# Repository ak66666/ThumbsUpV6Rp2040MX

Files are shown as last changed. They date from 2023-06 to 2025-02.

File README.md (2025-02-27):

# ThumbsUp! v6 RP2040-based keyboard for MX and ALPS switches

Multilevel 44 Key Split Contoured Keyboard.
2-key Thumb Cluster
   
* RP2040 is soldered on the boards.
* TRS (3-wire) audio cable to connect the halves.
* Hot swap sockets for MX switches, the ALPS need to be soldered in.
* USB-C connectors.
* Connects to computer from either side, halves could be used separately.

Board needs 3D printed switch plates: https://github.com/ak66666/ThubmsUpSwitchPlates

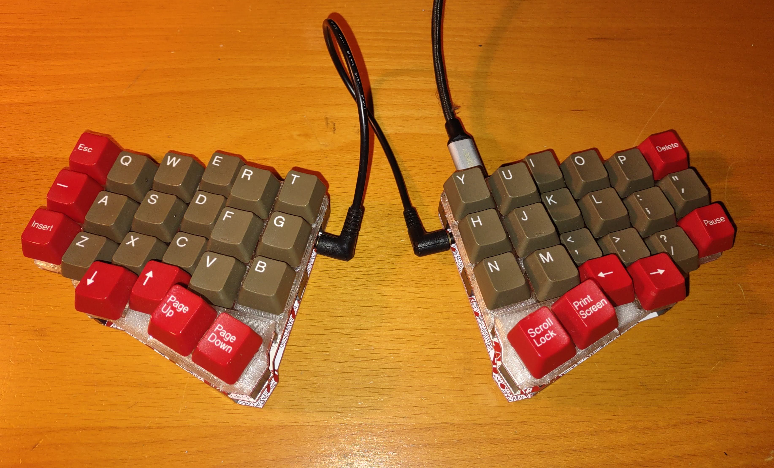
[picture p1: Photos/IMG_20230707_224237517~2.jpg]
Main view

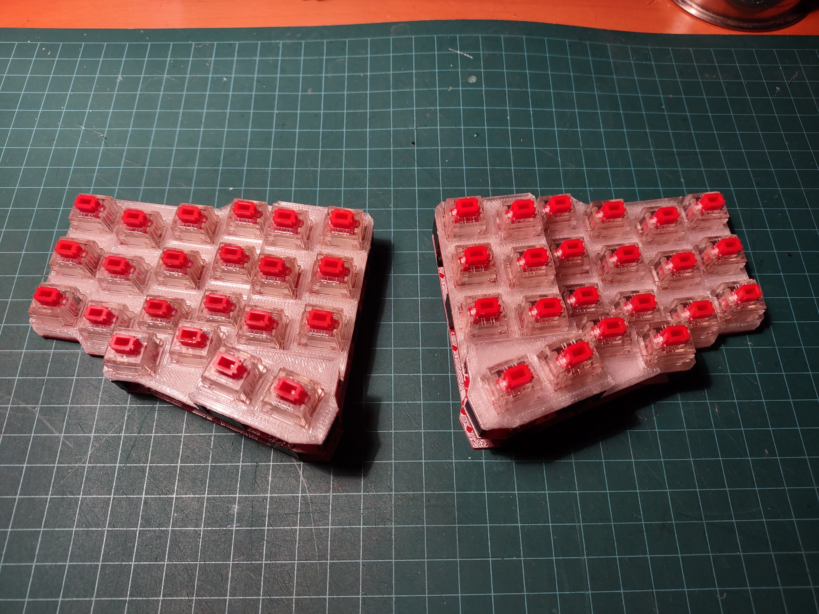
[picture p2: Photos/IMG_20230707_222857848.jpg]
ALPS Switches view


Other pictures in Photos folder.

# Firmware

Please refer to this article:
https://thumbsupkeyboards.blogspot.com/2024/02/source-files-and-default-firmware.html

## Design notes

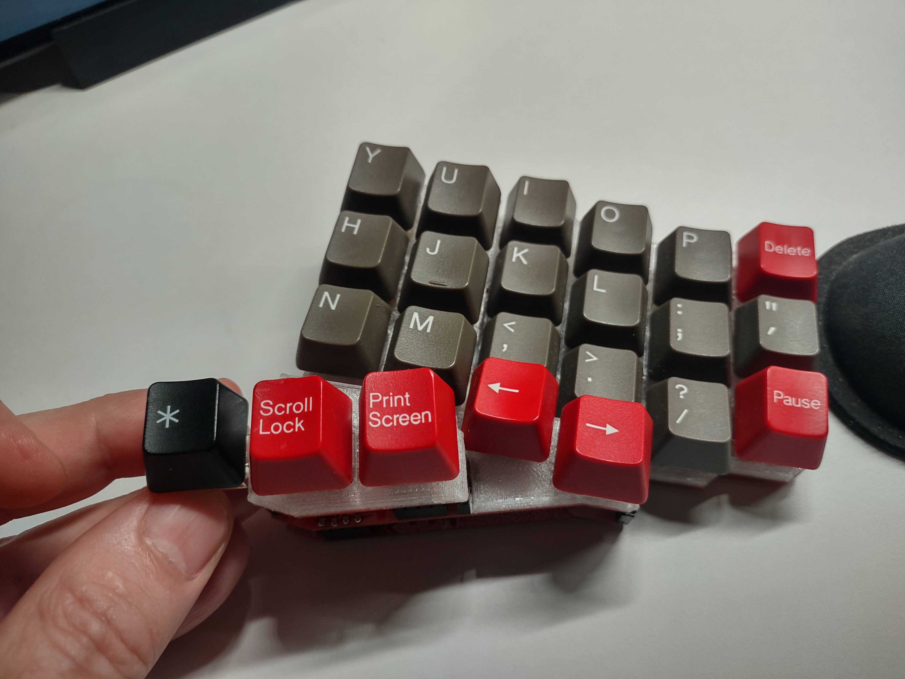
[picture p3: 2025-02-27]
Photos/IMG_20230818_104513918_HDR.jpg

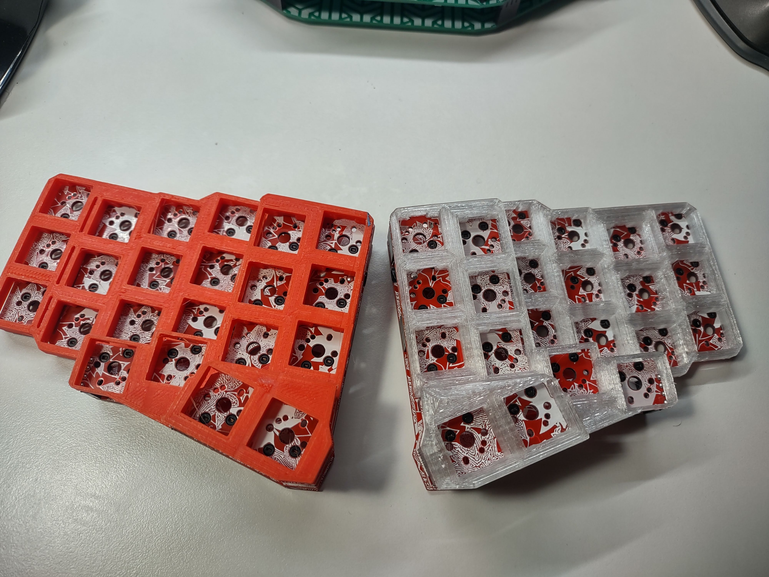
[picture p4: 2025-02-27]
Photos/IMG_20230814_161227283_HDR.jpg

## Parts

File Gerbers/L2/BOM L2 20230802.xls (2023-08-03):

Comment | Designator | Footprint | JLCPCB Part #
W25Q128JVSIM | IC2 | SOIC127P790X216-8N | C2613930
USB_C_Receptacle_USB2.0 | J32 | USB_C_Receptacle_Palconn_UTC16-G | C2927037
27pF | C5,C4 | C_0402_1005Metric | C1557
AMS1117-3.3_SOT223 | U1 | SOT229P700X180-4N | C6186
27.4 | R2,R1 | R_0402_1005Metric | C274349
10uF | C9 | C_0402_1005Metric | C15525
0.1uF | C17,C16,C15,C14,C13,C10,C7,C6,C2 | C_0402_1005Metric | C1525
5.1K | R9,R8,R4,R17 | R_0402_1005Metric | C25905
100uF | C11 | C_1210_3225Metric | C16133
1uF | C12,C3 | C_0402_1005Metric | C52923
Polyfuse | F1 | Fuse_1206_3216Metric | C2836286
1k | R6 | R_0402_1005Metric | C11702
RP2040 | IC1 | QFN40P700X700X90-57N-D | C2040
10K | R3,R7 | R_0402_1005Metric | C25744
ABLS-12.000MHZ-B4-T | Y1 | HC-49S-SMD | C2901753

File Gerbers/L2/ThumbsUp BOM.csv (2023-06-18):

Id | Designator | Package | Quantity | Designation | Supplier and ref
1 | G*** | LeavesW311 | 1 | LOGO
2 | MX20 | MX-1U-NoLED_HotSwap | 1 | SwG
3 | U1 | SOT229P700X180-4N | 1 | AMS1117-3.3_SOT223
4 | C11 | C_1210_3225Metric | 1 | 100uF
5 | RUN1,BOOTSEL1 | BUTT4 | 2 | BUTT-4
6 | R17,R4 | R_0402_1005Metric | 2 | 5.1K
7 | J50,J39,J45,J16 | PinHeader_1x04_P2.54mm_Vertical | 4 | Raiser_Male
8 | MX16 | MX-1U-NoLED_HotSwap | 1 | SwF
9 | MX21 | MX-1U-NoLED_HotSwap | 1 | SwB
10 | MX19 | MX-1U-NoLED_HotSwap | 1 | SwT
11 | MX17 | MX-1U-NoLED_HotSwap | 1 | SwV
12 | MX15 | MX-1U-NoLED_HotSwap | 1 | SwR
13 | MX14 | MX-1U-NoLED_HotSwap | 1 | SwLALT
14 | MX10 | MX-1U-NoLED_HotSwap | 1 | SwLWIN
15 | R2,R1 | R_0402_1005Metric | 2 | 27.4
16 | R9,R8 | R_0402_1005Metric | 2 | 5.1k
17 | R7 | R_0402_1005Metric | 1 | 10K
18 | R6 | R_0402_1005Metric | 1 | 1k
19 | R3 | R_0402_1005Metric | 1 | 10k
20 | C17,C16,C15,C14,C13,C10,C7,C6,C2 | C_0402_1005Metric | 9 | 0.1uF
21 | C12,C3 | C_0402_1005Metric | 2 | 1uF
22 | C9 | C_0402_1005Metric | 1 | 10uF
23 | C5,C4 | C_0402_1005Metric | 2 | 27pF
24 | J32 | USB_C_Receptacle_Palconn_UTC16-G | 1 | USB_C_Receptacle_USB2.0
25 | J3 | PinSocket_1x04_P2.54mm_Vertical | 1 | Conn_01x04_Female
26 | J36 | STX35013N | 1 | STX-3501-3N
27 | J17,J9,J13 | PinSocket_1x04_P2.54mm_Vertical | 3 | Raiser_Female
28 | J1,J8,J7 | PinHeader_1x04_P2.54mm_Vertical | 3 | Conn_01x04_Male
29 | Y1 | HC%2f49US-(AT49)_1 | 1 | ABLS-12.000MHZ-B4-T
30 | IC2 | SOIC127P790X216-8N | 1 | W25Q128JVSIM
31 | IC1 | QFN40P700X700X90-57N-D | 1 | RP2040
32 | F1 | Fuse_1206_3216Metric | 1 | Polyfuse

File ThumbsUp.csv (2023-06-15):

Id | Designator | Package | Quantity | Designation | Supplier and ref
1 | RUN,BOOTSEL | TL1016AAF220QG | 2 | TL1016AAF220QG
2 | IC1 | QFN40P700X700X90-57N-D | 1 | RP2040
3 | D25,D44,D43,D42,D41,D40,D39,D38,D37,D36,D35,D34,D33,D32,D31,D30,D29,D28,D27,D26,D24,D23,D22,D21,D20,D19,D18,D17,D16,D15,D14,D13,D12,D11,D10,D9,D8,D7,D6,D5,D4,D3,D2,D1 | D_SOD-123 | 44 | D_Small
4 | Y1 | HC%2f49US-(AT49)_1 | 1 | ABLS-12.000MHZ-B4-T
5 | R3 | R_0805_2012Metric | 1 | 10k
6 | IC2 | SOIC127P790X216-8N | 1 | W25Q128JVSIM
7 | C9,C11 | C_0805_2012Metric | 2 | 10uF
8 | C7,C6,C2,C1,C17,C16,C15,C14,C13,C10 | C_0805_2012Metric | 10 | 0.1uF
9 | C5,C4 | C_0805_2012Metric | 2 | 27pF
10 | C3,C12 | C_0805_2012Metric | 2 | 1uF
11 | U1 | SOT-223-3_TabPin2 | 1 | NCP1117-3.3_SOT223
12 | R7 | R_0805_2012Metric | 1 | DNF
13 | R6 | R_0805_2012Metric | 1 | 1k
14 | R5,R4 | R_0805_2012Metric | 2 | 4.7k
15 | R2,R1 | R_0805_2012Metric | 2 | 27.4
16 | F1 | Fuse_1206_3216Metric | 1 | Polyfuse
17 | USB1 | Molex-0548190589 | 1 | Molex-0548190589
18 | J27,J24,J25,J26,J6,J4 | PinHeader_1x04_P2.54mm_Vertical | 6 | Conn_01x04_Male
19 | J18,J10,J14 | PinHeader_1x04_P2.54mm_Vertical | 3 | Raiser_Male
20 | MX38 | Kailh_socket_PG1350_optional | 1 | SwMENU
21 | MX27 | Kailh_socket_PG1350_optional | 1 | SwU
22 | MX28 | Kailh_socket_PG1350_optional | 1 | SwJ
23 | MX29 | Kailh_socket_PG1350_optional | 1 | SwM
24 | MX34 | Kailh_socket_PG1350_optional | 1 | SwRALT
25 | J20,J21,J22,J23 | PinSocket_1x04_P2.54mm_Vertical | 4 | Conn_01x04_Female
26 | MX15 | Kailh_socket_PG1350_optional | 1 | SwR
27 | MX24 | Kailh_socket_PG1350_optional | 1 | SwH
28 | MX10 | Kailh_socket_PG1350_optional | 1 | SwLWIN
29 | MX14 | Kailh_socket_PG1350_optional | 1 | SwLALT
30 | MX17 | Kailh_socket_PG1350_optional | 1 | SwV
31 | MX25 | Kailh_socket_PG1350_optional | 1 | SwN
32 | MX19 | Kailh_socket_PG1350_optional | 1 | SwT
33 | MX21 | Kailh_socket_PG1350_optional | 1 | SwB
34 | MX20 | Kailh_socket_PG1350_optional | 1 | SwG
35 | MX23 | Kailh_socket_PG1350_optional | 1 | SwY
36 | MX16 | Kailh_socket_PG1350_optional | 1 | SwF
37 | J15,J11 | PinSocket_1x04_P2.54mm_Vertical | 2 | Raiser_Female

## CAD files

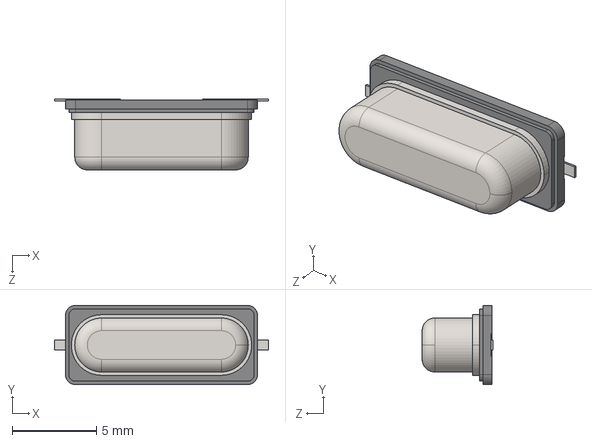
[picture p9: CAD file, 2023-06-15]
ABLS-12.000MHZ-B4-T/3D/ABLS-12.000MHZ-B4-T.stp
12.7 x 4.70 x 4.20 mm

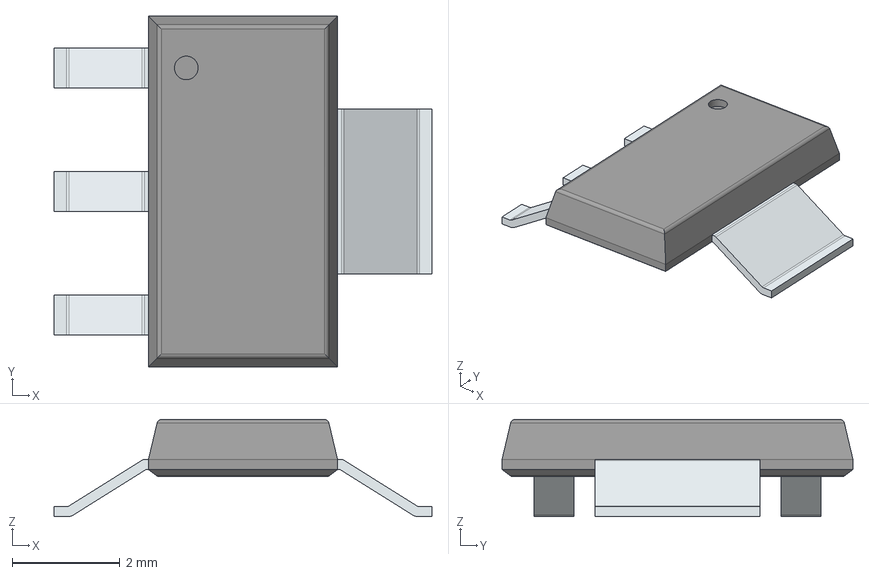
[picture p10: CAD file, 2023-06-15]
AMS1117-3.3/3D/AMS1117-3.3.stp
7.00 x 6.50 x 1.80 mm
PinsArrayL
FilletPinR

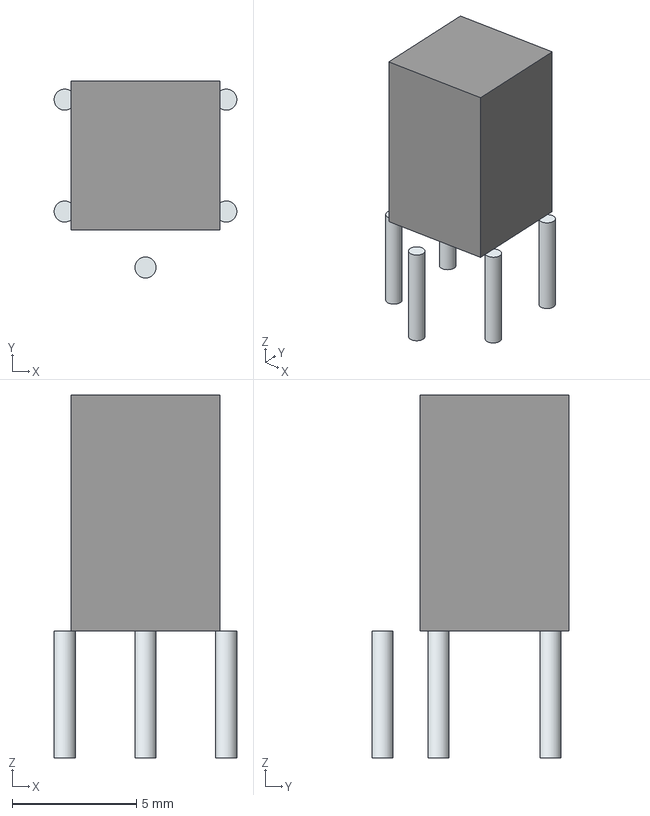
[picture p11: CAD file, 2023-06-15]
LIB_BUTT-4/BUTT-4/3D/BUTT-4.stp
7.35 x 7.92 x 14.6 mm
Leads x 5

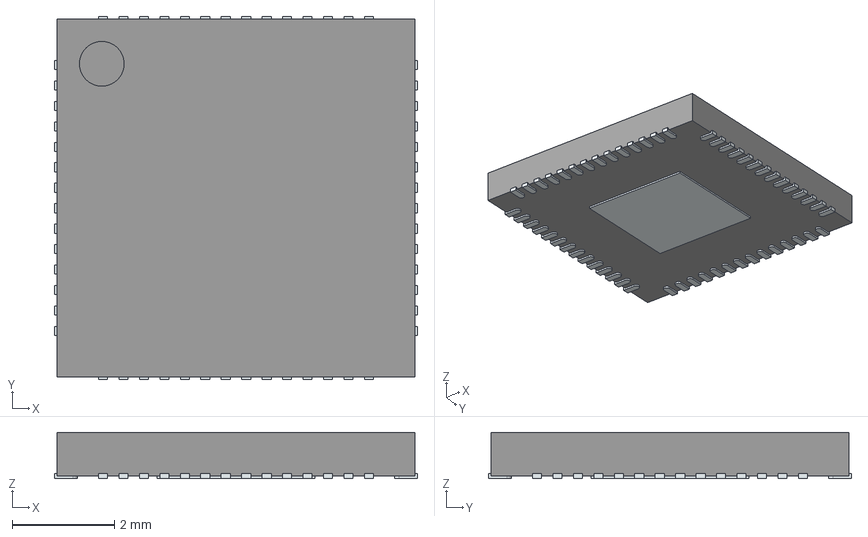
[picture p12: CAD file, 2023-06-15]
RP2040/3D/RP2040.stp
7.10 x 7.10 x 0.9 mm
ThermalPin
PinsArrayLR
PinsArrayTB

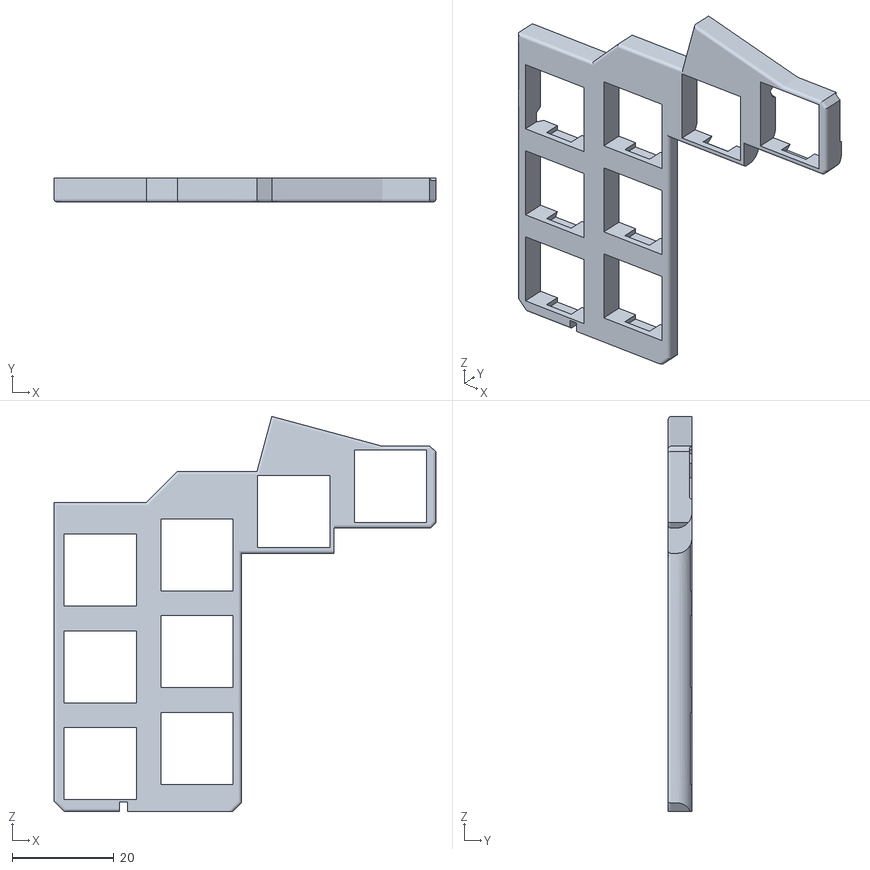
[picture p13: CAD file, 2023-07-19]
STL/L2.stl
75.2 x 4.70 x 77.8

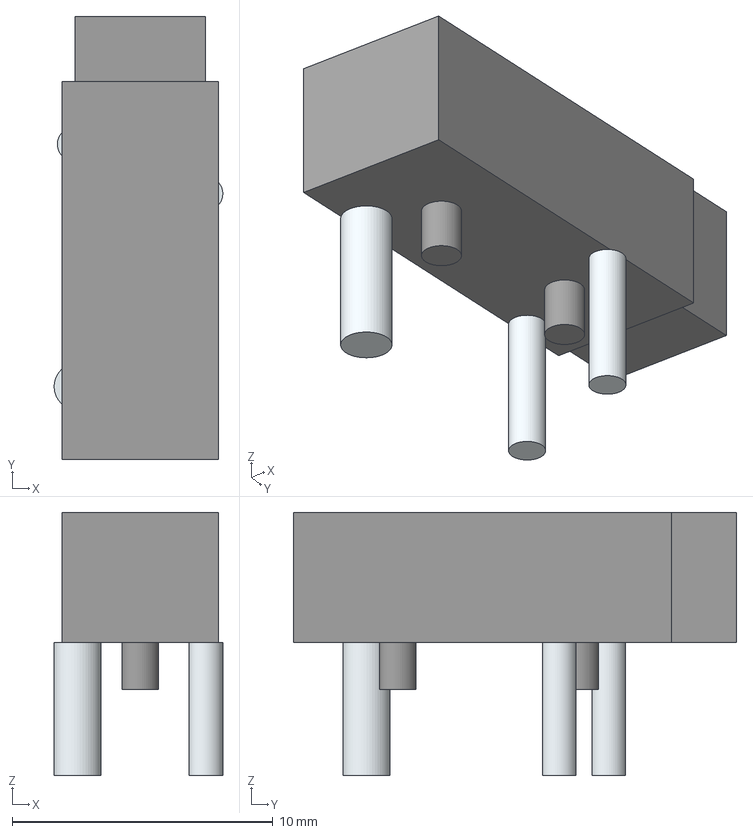
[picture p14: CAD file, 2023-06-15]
STX-3501-3N/3D/STX-3501-3N.stp
6.47 x 17.0 x 10.1 mm
Lugs
Leads

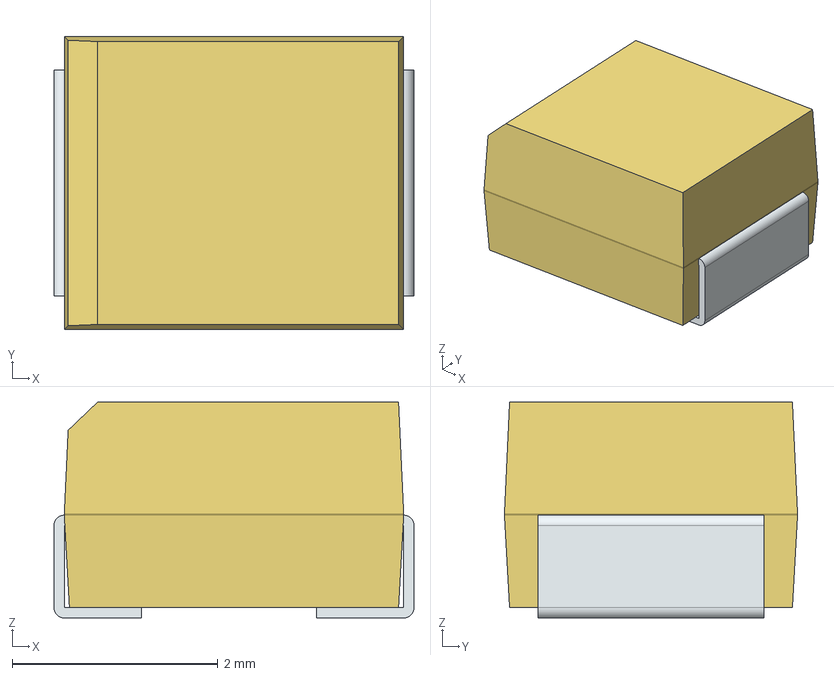
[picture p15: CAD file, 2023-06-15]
TAJB107K006RNJV/3D/TAJB107K006RNJV.stp
3.50 x 2.85 x 2.10 mm
FilletPin1
FilletPin2

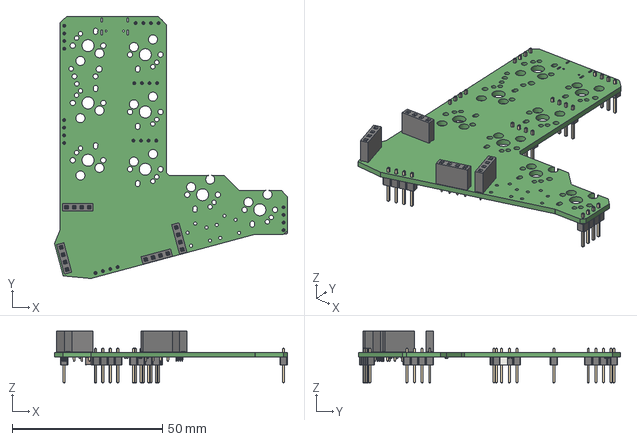
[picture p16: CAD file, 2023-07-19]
ThumbsUpL2.step
77.5 x 87.1 x 17.2 mm

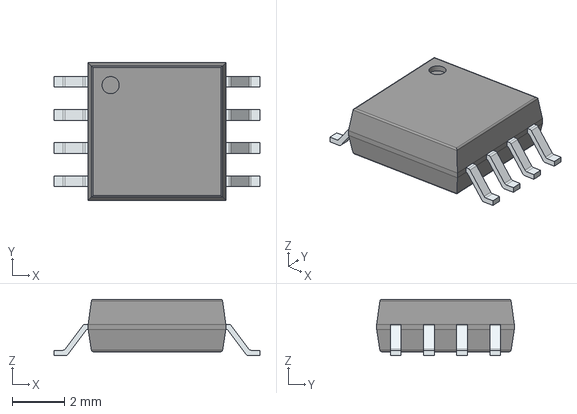
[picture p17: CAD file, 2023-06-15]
W25Q128JVSIM/3D/W25Q128JVSIM.stp
7.90 x 5.28 x 2.16 mm
PinsArrayLR

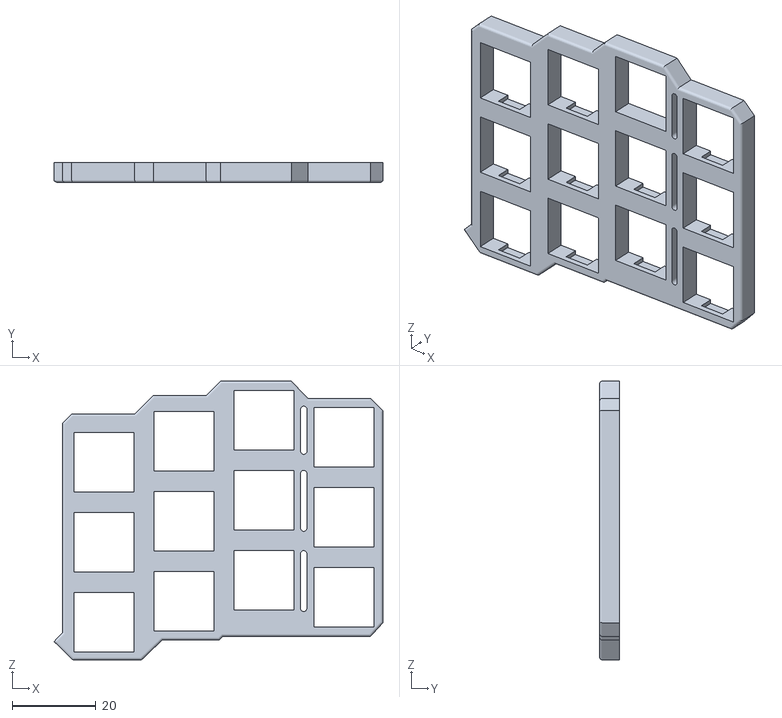
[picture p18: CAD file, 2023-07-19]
STL/L1.stl
78.4 x 4.70 x 66.4

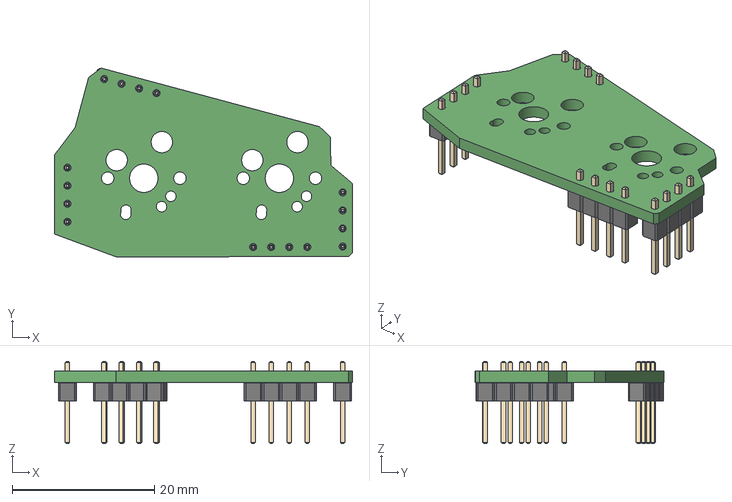
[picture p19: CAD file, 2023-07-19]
ThumbsUpL3.step
41.9 x 26.6 x 11.5 mm

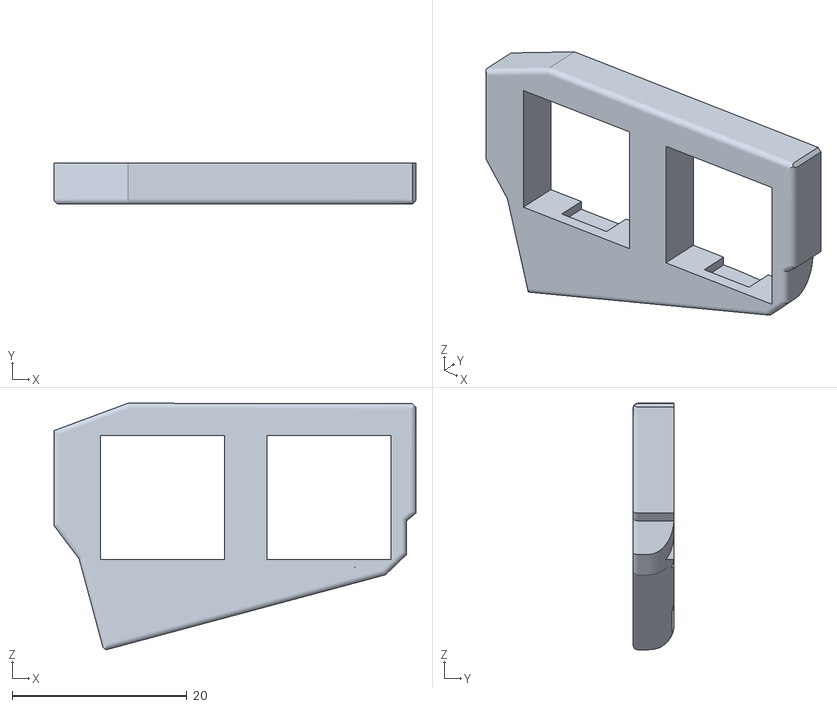
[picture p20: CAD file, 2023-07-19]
STL/L3.stl
41.4 x 4.70 x 28.2

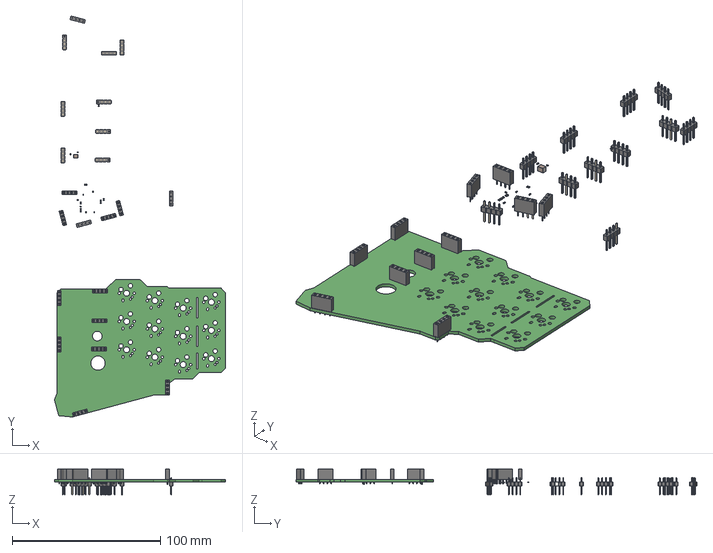
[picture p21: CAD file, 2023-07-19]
ThumbsUp.step
115.4 x 270.4 x 17.2 mm

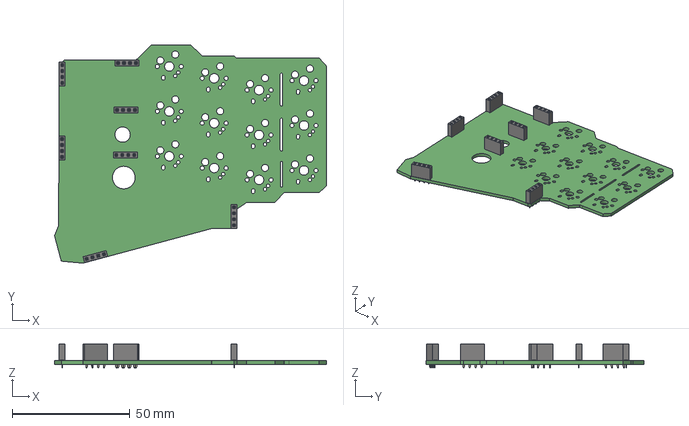
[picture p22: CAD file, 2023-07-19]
ThumbsUpL1.step
115.4 x 92.6 x 10.1 mm

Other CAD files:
ThumbsUp 3.step
ThumbsUp 2.step
Outline.dxf
105450-0101/3D/105450-0101.stp
ABLS-12.000MHZ-B4-T/Allegro/hc_49us-_at49__1.psm
ABLS-12.000MHZ-B4-T/DEHDL/abls_12.000mhz_b4_t/chips/chips.prt
AMS1117-3.3/Allegro/sot229p700x180-4n.psm
AMS1117-3.3/DEHDL/ams1117_3.3/chips/chips.prt
EVQ-P7B01P/Allegro/evqp7b01p.psm
EVQ-P7B01P/DEHDL/evq_p7b01p/chips/chips.prt
LIB_BUTT-4/BUTT-4/Allegro/butt4.psm
LIB_BUTT-4/BUTT-4/DEHDL/butt_4/chips/chips.prt
Molex 52559-1233/52559-1233/3D/52559-1233.stp
Molex 52559-1233/52559-1233/Allegro/525591233.psm
Molex 52559-1233/52559-1233/DEHDL/52559_1233/chips/chips.prt
RP2040/Allegro/qfn40p700x700x90-57n-d.psm
RP2040/DEHDL/rp2040/chips/chips.prt
STX-3501-3N/Allegro/stx35013n.psm
STX-3501-3N/DEHDL/stx_3501_3n/chips/chips.prt
TAJB107K006RNJV/Allegro/cappm3528x210n.psm
TAJB107K006RNJV/DEHDL/tajb107k006rnjv/chips/chips.prt
TL1016AAF220QG/Allegro/tl1016aaf220qg.psm
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

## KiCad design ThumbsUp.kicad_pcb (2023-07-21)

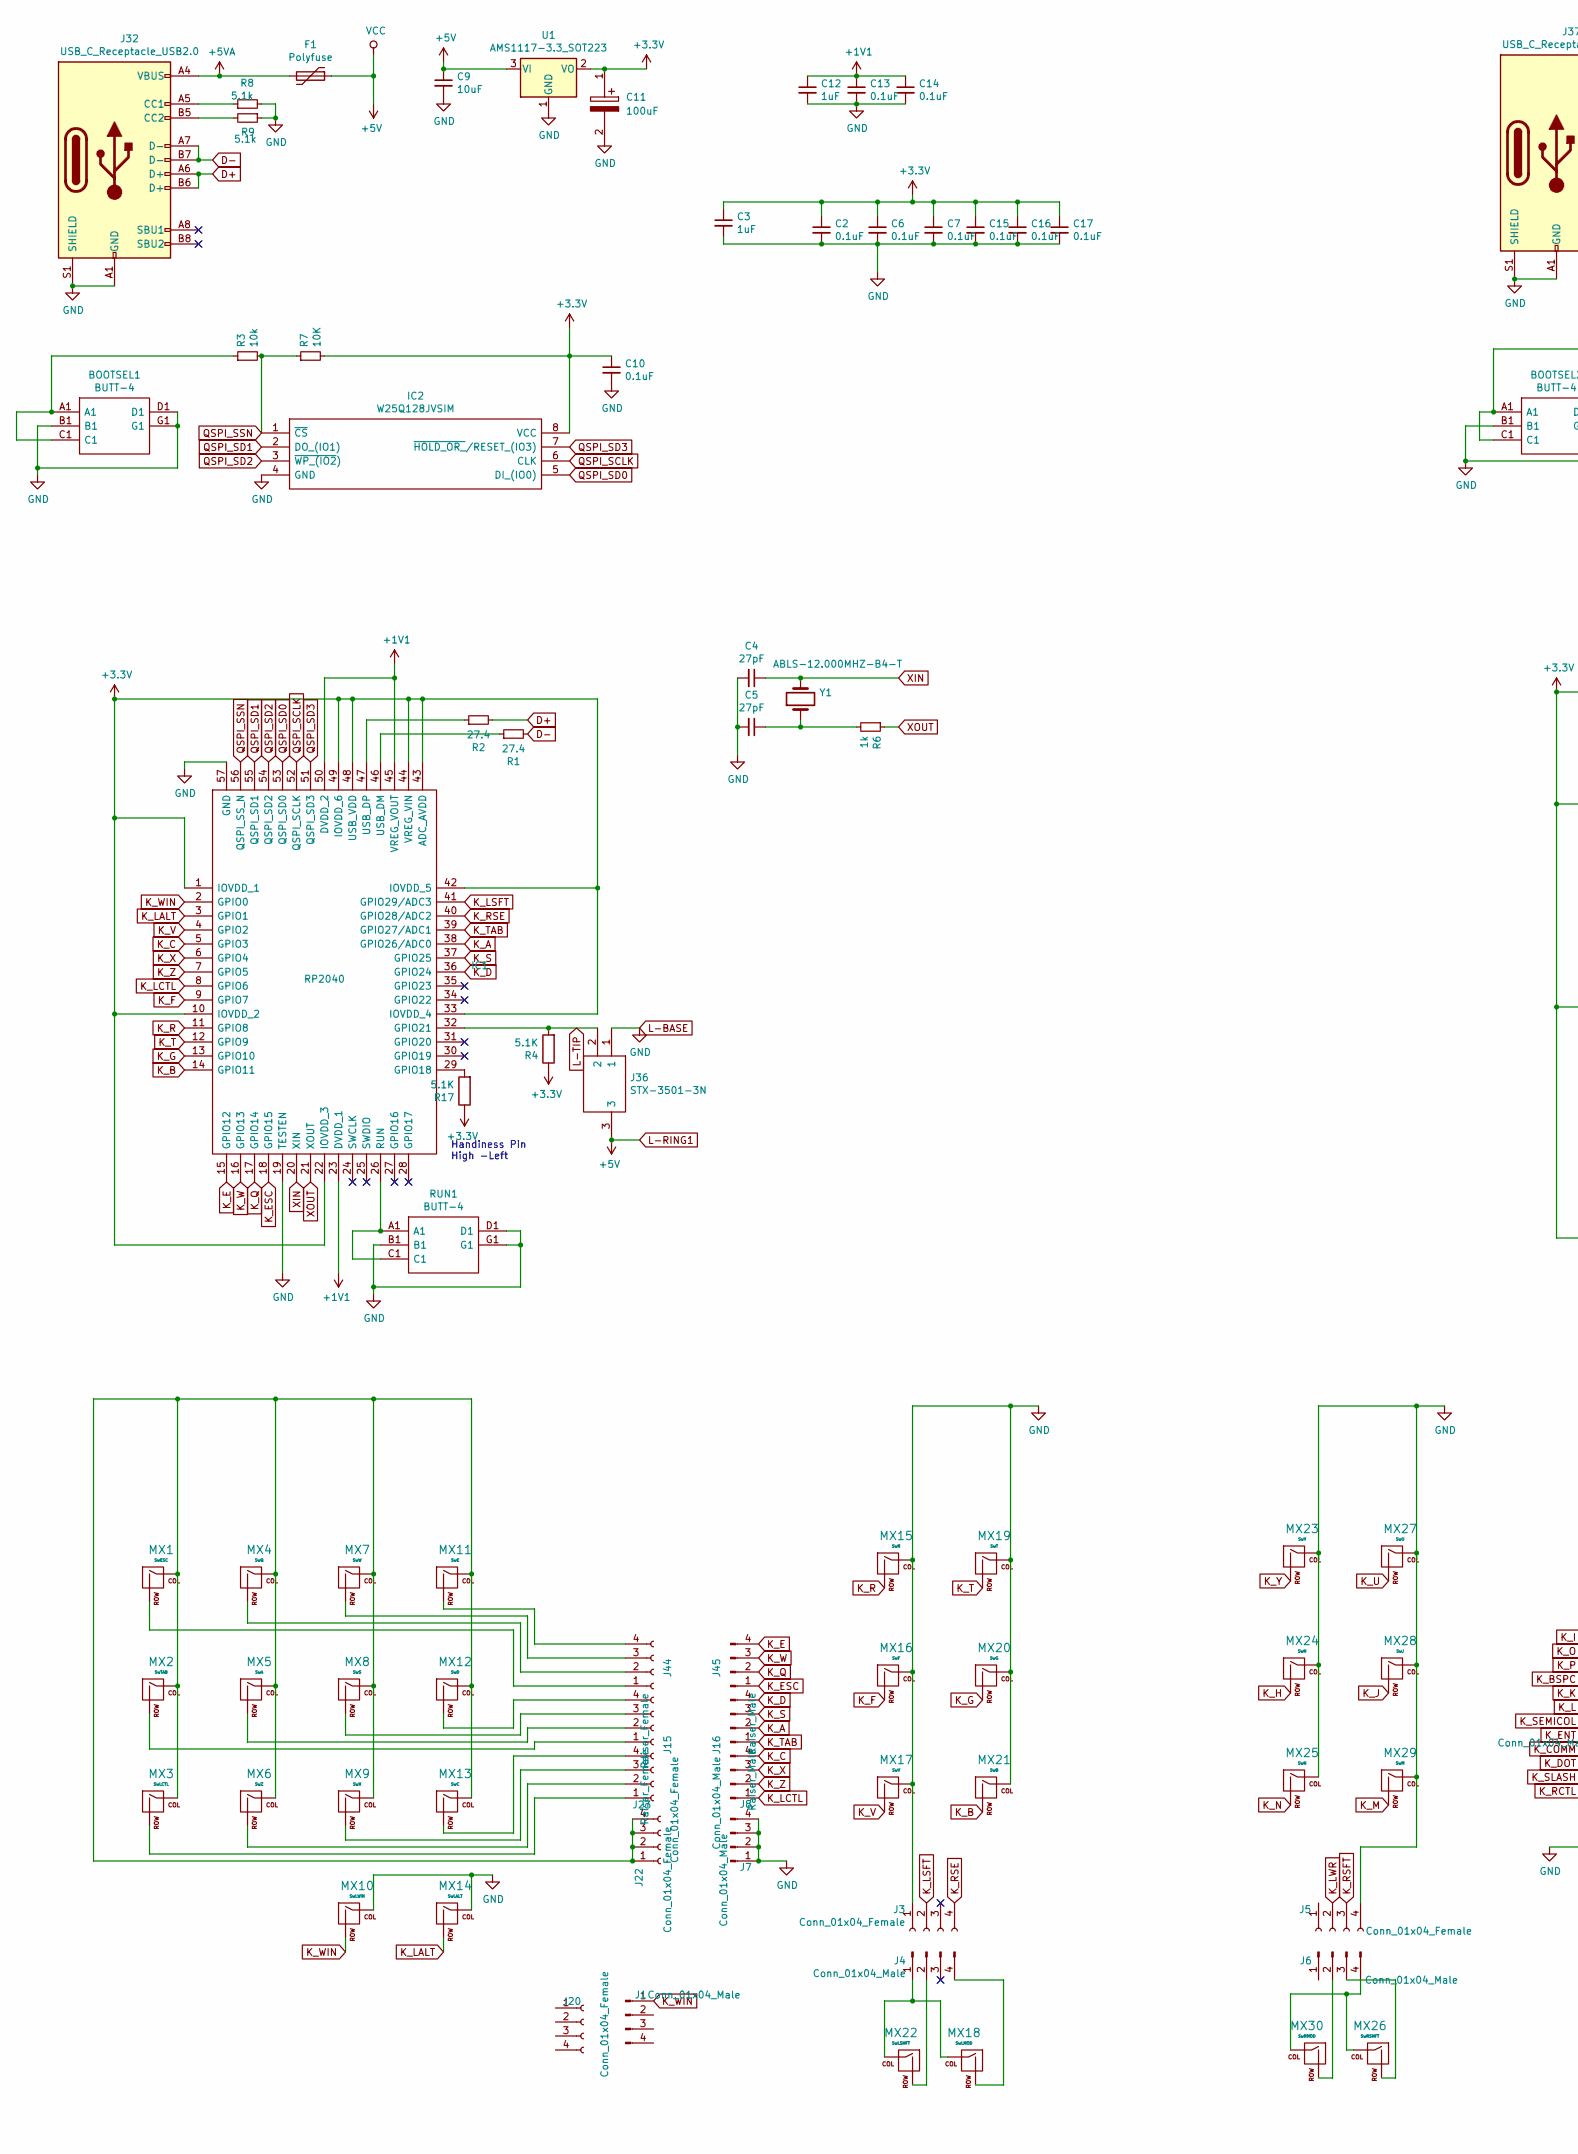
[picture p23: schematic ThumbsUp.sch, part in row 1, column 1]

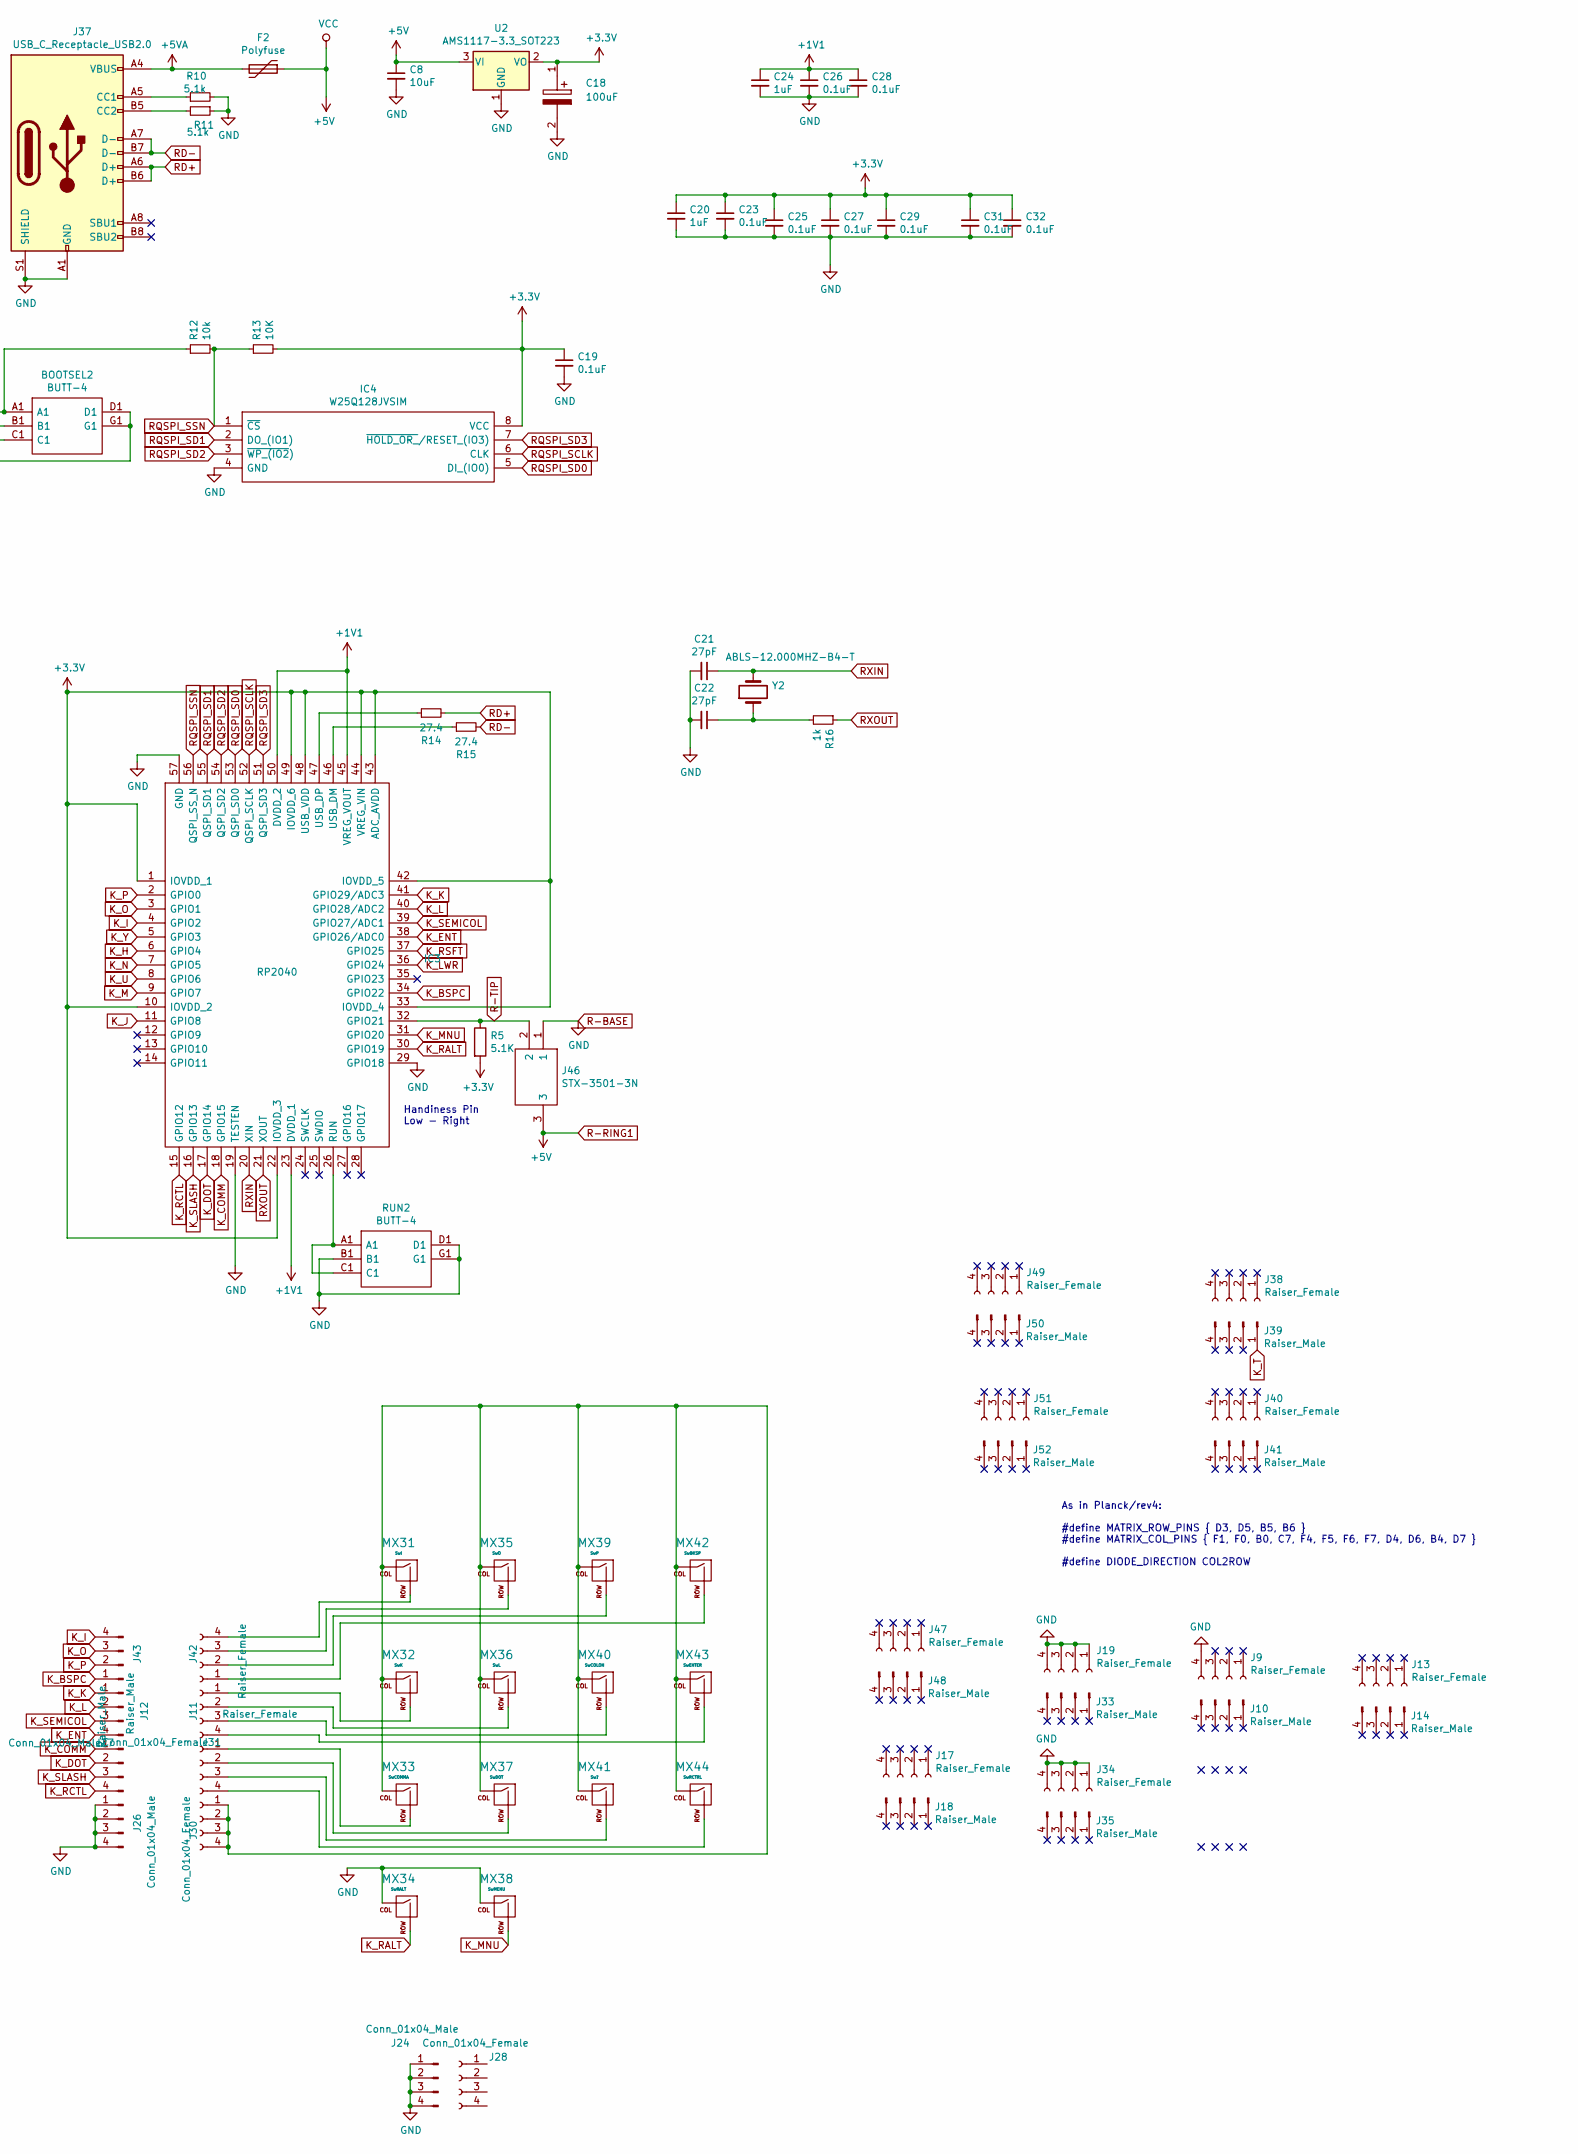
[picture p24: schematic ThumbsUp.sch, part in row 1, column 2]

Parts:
BOOTSEL1, BOOTSEL2: BUTT-4; BUTT4; Manufacturer_Part_Number BUTT-4; Mouser Part Number 992-BUTT-4
C2, C6, C7, C10, C13, C14, C15, C16, C17, C19, C23, C25, C26, C27, C28, C29, C31, C32: 0.1uF; C_0402_1005Metric
C3, C12, C20, C24: 1uF; C_0402_1005Metric
C4, C5, C21, C22: 27pF; C_0402_1005Metric
C8, C9: 10uF; C_0402_1005Metric
C11, C18: 100uF; C_1210_3225Metric
F1, F2: Polyfuse; Fuse_1206_3216Metric
IC1, IC3: RP2040; RP2040-QFN-56; Manufacturer_Part_Number RP2040
IC2, IC4: W25Q128JVSIM; SOIC127P790X216-8N; Manufacturer_Part_Number W25Q128JVSIM; Mouser Part Number 454-W25Q128JVSIM
J1, J4, J6, J7, J8, J24, J26, J27: Conn_01x04_Male; PinHeader_1x04_P2.54mm_Vertical
J3, J5, J20, J22, J23, J28, J30, J31: Conn_01x04_Female; PinSocket_1x04_P2.54mm_Vertical
J9, J11, J13, J15, J17, J19, J34, J38, J40, J42, J44, J47, J49, J51: Raiser_Female; PinSocket_1x04_P2.54mm_Vertical
J10, J12, J14, J16, J18, J33, J35, J39, J41, J43, J45, J48, J50, J52: Raiser_Male; PinHeader_1x04_P2.54mm_Vertical
J32, J37: USB_C_Receptacle_USB2.0; USB_C_Receptacle_Palconn_UTC16-G
J36, J46: STX-3501-3N; STX35013N; Manufacturer_Part_Number STX-3501-3N; Mouser Part Number 806-STX-3501-3N
MX1: SwESC; MX-1U-NoLED_HotSwap
MX2: SwTAB; MX-1U-NoLED_HotSwap
MX3: SwLCTL; MX-1U-NoLED_HotSwap
MX4: SwQ; MX-1U-NoLED_HotSwap
MX5: SwA; MX-1U-NoLED_HotSwap
MX6: SwZ; MX-1U-NoLED_HotSwap
MX7: SwW; MX-1U-NoLED_HotSwap
MX8: SwS; MX-1U-NoLED_HotSwap
MX9: SwX; MX-1U-NoLED_HotSwap
MX10: SwLWIN; MX-1U-NoLED_HotSwap
MX11: SwE; MX-1U-NoLED_HotSwap
MX12: SwD; MX-1U-NoLED_HotSwap
MX13: SwC; MX-1U-NoLED_HotSwap
MX14: SwLALT; MX-1U-NoLED_HotSwap
MX15: SwR; MX-1U-NoLED_HotSwap
MX16: SwF; MX-1U-NoLED_HotSwap
MX17: SwV; MX-1U-NoLED_HotSwap
MX18: SwLMOD; MX-1U-NoLED_HotSwap
MX19: SwT; MX-1U-NoLED_HotSwap
MX20: SwG; MX-1U-NoLED_HotSwap
MX21: SwB; MX-1U-NoLED_HotSwap
MX22: SwLSHFT; MX-1U-NoLED_HotSwap
MX23: SwY; MX-1U-NoLED_HotSwap
MX24: SwH; MX-1U-NoLED_HotSwap
MX25: SwN; MX-1U-NoLED_HotSwap
MX26: SwRSHFT; MX-1U-NoLED_HotSwap
MX27: SwU; MX-1U-NoLED_HotSwap
MX28: SwJ; MX-1U-NoLED_HotSwap
MX29: SwM; MX-1U-NoLED_HotSwap
MX30: SwRMOD; MX-1U-NoLED_HotSwap
MX31: SwI; MX-1U-NoLED_HotSwap
MX32: SwK; MX-1U-NoLED_HotSwap
MX33: SwCOMMA; MX-1U-NoLED_HotSwap
MX34: SwRALT; MX-1U-NoLED_HotSwap
MX35: SwO; MX-1U-NoLED_HotSwap
MX36: SwL; MX-1U-NoLED_HotSwap
MX37: SwDOT; MX-1U-NoLED_HotSwap
MX38: SwMENU; MX-1U-NoLED_HotSwap
MX39: SwP; MX-1U-NoLED_HotSwap
MX40: SwCOLON; MX-1U-NoLED_HotSwap
MX41: Sw?; MX-1U-NoLED_HotSwap
MX42: SwBKSP; MX-1U-NoLED_HotSwap
MX43: SwENTER; MX-1U-NoLED_HotSwap
MX44: SwRCTRL; MX-1U-NoLED_HotSwap
R1, R2, R14, R15: 27.4; R_0402_1005Metric
R3, R12: 10k; R_0402_1005Metric
R4, R5, R17: 5.1K; R_0402_1005Metric
R6, R16: 1k; R_0402_1005Metric
R7, R13: 10K; R_0402_1005Metric
R8, R9, R10, R11: 5.1k; R_0402_1005Metric
RUN1, RUN2: BUTT-4; BUTT4; Manufacturer_Part_Number BUTT-4; Mouser Part Number 992-BUTT-4
U1, U2: AMS1117-3.3_SOT223; SOT229P700X180-4N
Y1, Y2: ABLS-12.000MHZ-B4-T; HC%2f49US-(AT49)_1

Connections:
+1V1: C12.1, C13.1, C14.1, C24.1, C26.1, C28.1, IC1.23 (DVDD_1), IC1.45 (VREG_VOUT), IC1.50 (DVDD_2), IC3.23 (DVDD_1), IC3.45 (VREG_VOUT), IC3.50 (DVDD_2)
+3V3: C2.1, C3.1, C6.1, C7.1, C10.1, C11.1, C15.1, C16.1, C17.1, C18.1, C19.1, C20.1, C23.1, C25.1, C27.1, C29.1, C31.1, C32.1, IC1.1 (IOVDD_1), IC1.10 (IOVDD_2), IC1.22 (IOVDD_3), IC1.33 (IOVDD_4), IC1.42 (IOVDD_5), IC1.43 (ADC_AVDD), IC1.44 (VREG_VIN), IC1.48 (USB_VDD), IC1.49 (IOVDD_6), IC2.8 (VCC), IC3.1 (IOVDD_1), IC3.10 (IOVDD_2), IC3.22 (IOVDD_3), IC3.33 (IOVDD_4), IC3.42 (IOVDD_5), IC3.43 (ADC_AVDD), IC3.44 (VREG_VIN), IC3.48 (USB_VDD), IC3.49 (IOVDD_6), IC4.8 (VCC), R4.1, R5.2, R7.2, R13.2, R17.1, U1.2 (VO), U2.2 (VO)
+5VA: F1.2, F2.2, J32.A4 (VBUS), J32.A9 (VBUS), J32.B4 (VBUS), J32.B9 (VBUS), J37.A4 (VBUS), J37.A9 (VBUS), J37.B4 (VBUS), J37.B9 (VBUS)
D+: J32.A6 (D+), J32.B6 (D+), R2.2
D-: J32.A7 (D-), J32.B7 (D-), R1.2
K_A: IC1.38 (GPIO26/ADC0), J16.2
K_B: IC1.14 (GPIO11), MX21.2 (ROW)
K_BSPC: IC3.34 (GPIO22), J43.1
K_C: IC1.5 (GPIO3), J8.4
K_COMM: IC3.18 (GPIO15), J27.1
K_D: IC1.36 (GPIO24), J16.4
K_DOT: IC3.17 (GPIO14), J27.2
K_E: IC1.15 (GPIO12), J45.4
K_ENT: IC3.38 (GPIO26/ADC0), J12.4
K_ESC: IC1.18 (GPIO15), J45.1
K_F: IC1.9 (GPIO7), MX16.2 (ROW)
K_G: IC1.13 (GPIO10), MX20.2 (ROW)
K_H: IC3.6 (GPIO4), MX24.2 (ROW)
K_I: IC3.4 (GPIO2), J43.4
K_J: IC3.11 (GPIO8), MX28.2 (ROW)
K_K: IC3.41 (GPIO29/ADC3), J12.1
K_L: IC3.40 (GPIO28/ADC2), J12.2
K_LALT: IC1.3 (GPIO1), MX14.2 (ROW)
K_LCTL: IC1.8 (GPIO6), J8.1
K_LSFT: IC1.41 (GPIO29/ADC3), J3.2
K_LWR: IC3.36 (GPIO24), J5.2
K_M: IC3.9 (GPIO7), MX29.2 (ROW)
K_MNU: IC3.31 (GPIO20), MX38.2 (ROW)
K_N: IC3.7 (GPIO5), MX25.2 (ROW)
K_O: IC3.3 (GPIO1), J43.3
K_P: IC3.2 (GPIO0), J43.2
K_Q: IC1.17 (GPIO14), J45.2
K_R: IC1.11 (GPIO8), MX15.2 (ROW)
K_RALT: IC3.30 (GPIO19), MX34.2 (ROW)
K_RCTL: IC3.15 (GPIO12), J27.4
K_RSE: IC1.40 (GPIO28/ADC2), J3.4
K_RSFT: IC3.37 (GPIO25), J5.3
K_S: IC1.37 (GPIO25), J16.3
K_SEMICOL: IC3.39 (GPIO27/ADC1), J12.3
K_SLASH: IC3.16 (GPIO13), J27.3
K_T: IC1.12 (GPIO9), J39.1, MX19.2 (ROW)
K_TAB: IC1.39 (GPIO27/ADC1), J16.1
K_U: IC3.8 (GPIO6), MX27.2 (ROW)
K_V: IC1.4 (GPIO2), MX17.2 (ROW)
K_W: IC1.16 (GPIO13), J45.3
K_WIN: IC1.2 (GPIO0), J1.1, MX10.2 (ROW)
K_X: IC1.6 (GPIO4), J8.3
K_Y: IC3.5 (GPIO3), MX23.2 (ROW)
K_Z: IC1.7 (GPIO5), J8.2
L-BASE: BOOTSEL1.B1, BOOTSEL1.D1, BOOTSEL1.G1, BOOTSEL2.B1, BOOTSEL2.D1, BOOTSEL2.G1, C2.2, C3.2, C4.2, C5.2, C6.2, C7.2, C8.2, C9.2, C10.2, C11.2, C12.2, C13.2, C14.2, C15.2, C16.2, C17.2, C18.2, C19.2, C20.2, C21.2, C22.2, C23.2, C24.2, C25.2, C26.2, C27.2, C28.2, C29.2, C31.2, C32.2, IC1.19 (TESTEN), IC1.57 (GND), IC2.4 (GND), IC3.19 (TESTEN), IC3.29 (GPIO18), IC3.57 (GND), IC4.4 (GND), J3.1, J5.4, J7.1, J7.2, J7.3, J7.4, J9.4, J19.1, J19.2, J19.3, J19.4, J24.1, J24.2, J24.3, J24.4, J26.1, J26.2, J26.3, J26.4, J32.A1 (GND), J32.A12 (GND), J32.B1 (GND), J32.B12 (GND), J32.S1 (SHIELD), J34.1, J34.2, J34.3, J34.4, J36.1, J37.A1 (GND), J37.A12 (GND), J37.B1 (GND), J37.B12 (GND), J37.S1 (SHIELD), J46.1, MX10.1 (COL), MX14.1 (COL), MX15.1 (COL), MX16.1 (COL), MX17.1 (COL), MX19.1 (COL), MX20.1 (COL), MX21.1 (COL), MX23.1 (COL), MX24.1 (COL), MX25.1 (COL), MX27.1 (COL), MX28.1 (COL), MX29.1 (COL), MX34.1 (COL), MX38.1 (COL), R8.2, R9.1, R10.2, R11.1, RUN1.B1, RUN1.D1, RUN1.G1, RUN2.B1, RUN2.D1, RUN2.G1, U1.1 (GND), U2.1 (GND)
L-RING1: C8.1, C9.1, F1.1, F2.1, J36.3, J46.3, U1.3 (VI), U2.3 (VI)
L-TIP: IC1.32 (GPIO21), J36.2, R4.2
unnamed: BOOTSEL1.A1, BOOTSEL1.C1, R3.1
unnamed: BOOTSEL2.A1, BOOTSEL2.C1, R12.1
unnamed: C5.1, R6.2, Y1.1
unnamed: C22.1, R16.2, Y2.1
unnamed: IC1.26 (RUN), RUN1.A1, RUN1.C1
unnamed: IC1.29 (GPIO18), R17.2
unnamed: IC1.46 (USB_DM), R1.1
unnamed: IC1.47 (USB_DP), R2.1
unnamed: IC3.26 (RUN), RUN2.A1, RUN2.C1
unnamed: IC3.46 (USB_DM), R15.1
unnamed: IC3.47 (USB_DP), R14.1
unnamed: J4.1, MX18.1 (COL), MX22.1 (COL)
unnamed: J4.2, MX22.2 (ROW)
unnamed: J4.4, MX18.2 (ROW)
unnamed: J6.2, MX30.2 (ROW)
unnamed: J6.3, MX26.2 (ROW)
unnamed: J6.4, MX26.1 (COL), MX30.1 (COL)
unnamed: J11.1, MX32.2 (ROW)
unnamed: J11.2, MX36.2 (ROW)
unnamed: J11.3, MX40.2 (ROW)
unnamed: J11.4, MX43.2 (ROW)
unnamed: J15.1, MX2.2 (ROW)
unnamed: J15.2, MX5.2 (ROW)
unnamed: J15.3, MX8.2 (ROW)
unnamed: J15.4, MX12.2 (ROW)
unnamed: J22.1, J22.2, J22.3, J22.4, MX1.1 (COL), MX2.1 (COL), MX3.1 (COL), MX4.1 (COL), MX5.1 (COL), MX6.1 (COL), MX7.1 (COL), MX8.1 (COL), MX9.1 (COL), MX11.1 (COL), MX12.1 (COL), MX13.1 (COL)
unnamed: J23.1, MX3.2 (ROW)
unnamed: J23.2, MX6.2 (ROW)
unnamed: J23.3, MX9.2 (ROW)
unnamed: J23.4, MX13.2 (ROW)
unnamed: J30.1, J30.2, J30.3, J30.4, MX31.1 (COL), MX32.1 (COL), MX33.1 (COL), MX35.1 (COL), MX36.1 (COL), MX37.1 (COL), MX39.1 (COL), MX40.1 (COL), MX41.1 (COL), MX42.1 (COL), MX43.1 (COL), MX44.1 (COL)
unnamed: J31.1, MX33.2 (ROW)
unnamed: J31.2, MX37.2 (ROW)
unnamed: J31.3, MX41.2 (ROW)
unnamed: J31.4, MX44.2 (ROW)
unnamed: J32.A5 (CC1), R8.1
unnamed: J32.B5 (CC2), R9.2
unnamed: J37.A5 (CC1), R10.1
unnamed: J37.B5 (CC2), R11.2
unnamed: J42.1, MX42.2 (ROW)
unnamed: J42.2, MX39.2 (ROW)
unnamed: J42.3, MX35.2 (ROW)
unnamed: J42.4, MX31.2 (ROW)
unnamed: J44.1, MX1.2 (ROW)
unnamed: J44.2, MX4.2 (ROW)
unnamed: J44.3, MX7.2 (ROW)
unnamed: J44.4, MX11.2 (ROW)
QSPI_SCLK: IC1.52 (QSPI_SCLK), IC2.6 (CLK)
QSPI_SD0: IC1.53 (QSPI_SD0), IC2.5 (DI_(IO0))
QSPI_SD1: IC1.55 (QSPI_SD1), IC2.2 (DO_(IO1))
QSPI_SD2: IC1.54 (QSPI_SD2), IC2.3 (~WP_(IO2))
QSPI_SD3: IC1.51 (QSPI_SD3), IC2.7 (~HOLD_OR_~/RESET_(IO3))
QSPI_SSN: IC1.56 (QSPI_SS_N), IC2.1 (~CS), R3.2, R7.1
R-TIP: IC3.32 (GPIO21), J46.2, R5.1
RD+: J37.A6 (D+), J37.B6 (D+), R14.2
RD-: J37.A7 (D-), J37.B7 (D-), R15.2
RQSPI_SCLK: IC3.52 (QSPI_SCLK), IC4.6 (CLK)
RQSPI_SD0: IC3.53 (QSPI_SD0), IC4.5 (DI_(IO0))
RQSPI_SD1: IC3.55 (QSPI_SD1), IC4.2 (DO_(IO1))
RQSPI_SD2: IC3.54 (QSPI_SD2), IC4.3 (~WP_(IO2))
RQSPI_SD3: IC3.51 (QSPI_SD3), IC4.7 (~HOLD_OR_~/RESET_(IO3))
RQSPI_SSN: IC3.56 (QSPI_SS_N), IC4.1 (~CS), R12.2, R13.1
RXIN: C21.1, IC3.20 (XIN), Y2.2
RXOUT: IC3.21 (XOUT), R16.1
XIN: C4.1, IC1.20 (XIN), Y1.2
XOUT: IC1.21 (XOUT), R6.1

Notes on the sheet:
As in Planck/rev4: #define MATRIX_ROW_PINS { D3, D5, B5, B6 } #define MATRIX_COL_PINS { F1, F0, B0, C7, F4, F5, F6, F7, D4, D6, B4, D7 } #define DIODE_DIRECTION COL2ROW
Handiness Pin High -Left
Handiness Pin Low - Right

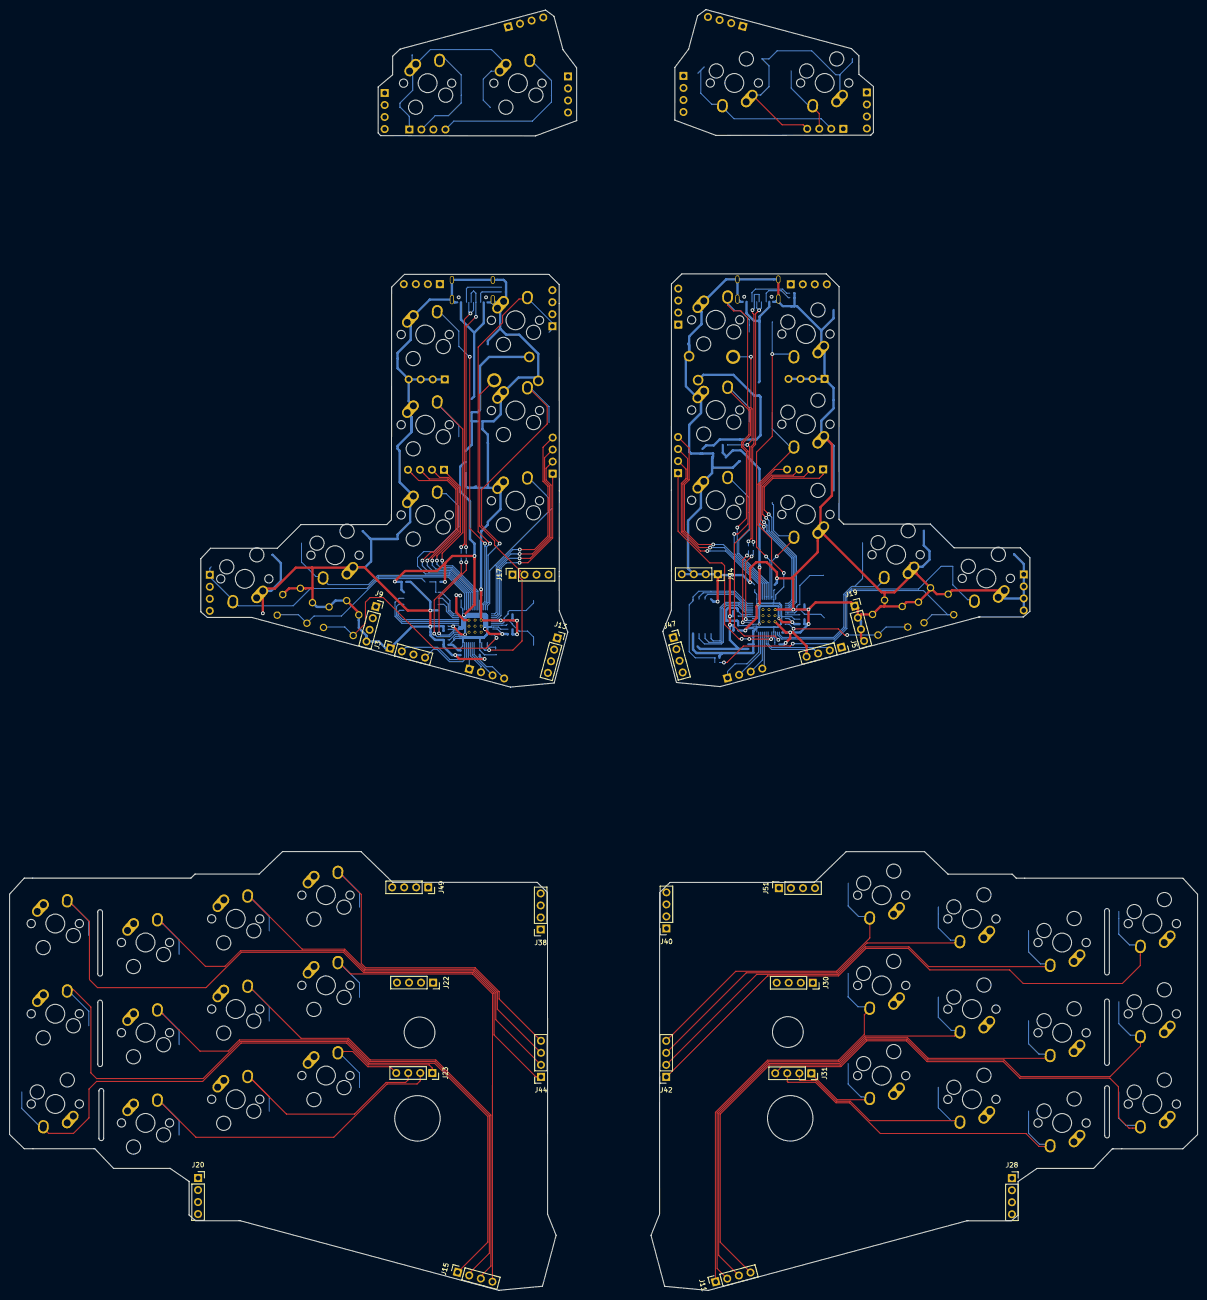
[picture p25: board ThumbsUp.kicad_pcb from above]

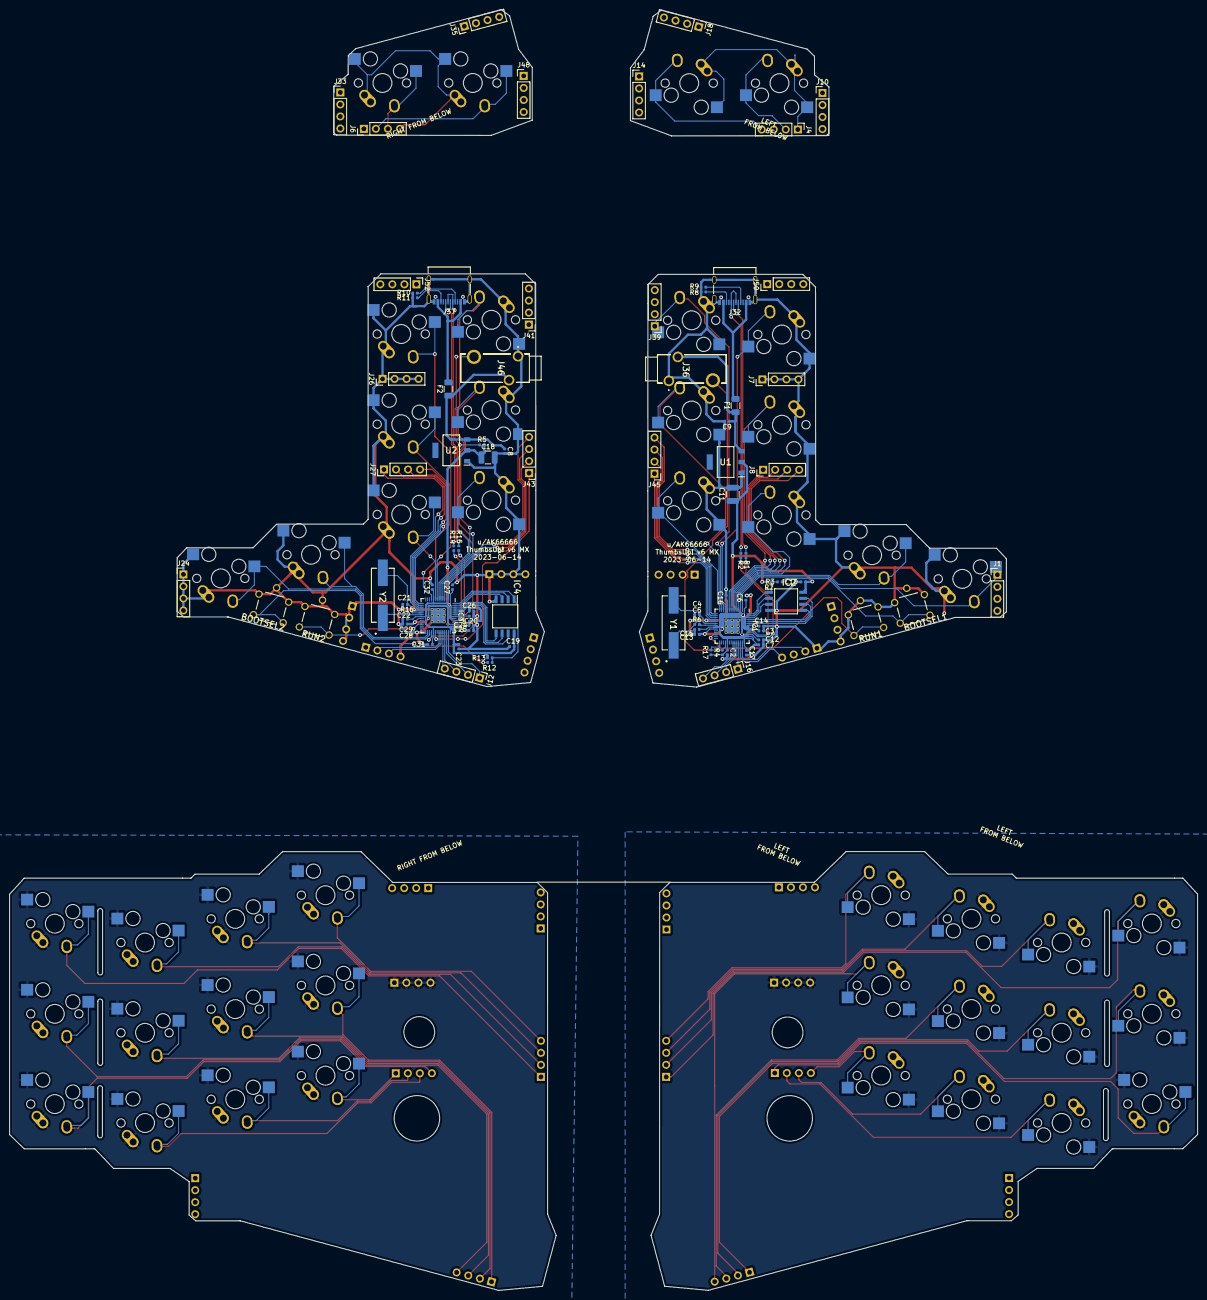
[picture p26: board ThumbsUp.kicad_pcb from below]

Board: 2 copper layers, 250.8 x 270.5 mm, 153 parts (87 on the bottom side), 118 nets.

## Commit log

2023-06-15 Initial check-in of v6
    [105450-0101.stp, 52559-1233.stp, 525591233.psm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]
2023-06-15 Removed the top row in schematics and PCBs, redrew the tracks
    [ThumbsUp.kicad_pcb, ThumbsUp.sch]
2023-06-17 Added new silkscreen, trying to apply it.
2023-06-18 Joined the L2 and R2 to save on setting up.
    [BOM v4 L2.xls, ThumbsUp BOM.csv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]
2023-06-18 Reverted the joining step - made the L2 and R2 separate again. The LR2 gerbers and PCB files are still there, so may return to this idea later on.
2023-07-19 Re-wired L2 RP2040 and memory as per manual
    [L1.stl, L2.stl, L3.stl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]
2023-07-19 Re-wired R2 RP2040 and memory as per manual
    [ThumbsUp.kicad_pcb]
2023-07-21 Re-wired R2 RP2040 - moved the R, C around it.
    [ThumbsUp.kicad_pcb]
2023-07-28 Fixed tracks too close to vias, applied silkscreen to Level 2
2023-07-28 Renerated Gerbers, POS, BOMs for Level 2
    [ThumbsUp-B_Cu.gbr, ThumbsUp-B_Mask.gbr, ThumbsUp-B_Paste.gbr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]
2023-08-03 Re-defined POS, BOMs for Level 2, as ordered on 20230803
    [BOM L2 20230802.xls, BOM R2 20230803.xls, BOM v4 L2.xls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]
